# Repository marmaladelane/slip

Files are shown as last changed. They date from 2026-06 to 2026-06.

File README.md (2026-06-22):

# K1 Smart Lighting Interface to PIR (SLIP)

For the [Smart Lighting](https://github.com/marmaladelane/smart-lighting) project, we need a way to connect PIR sensors to the smart lighting controller.

The most common and easily available outdoor (weatherproof) PIR sensors are the mains-powered ones, usually used to control lights directly. In theory we should be able to monitor the switched live (SL) output from one of these devices, using a device with a mains voltage level input, such as a [Sonoff ZBMINIR2](https://help.sonoff.tech/docs/zbminir2).

Unfortunately, this [does not work](https://electronics.stackexchange.com/questions/769672/sonoff-zbminir2-switched-live-input-from-pir-sensor), probably because a snubber network inside the PIR sensor, across the relay output contacts, leaks enough current to trigger the Sonoff's AC input (S2) even when the output is off. I couldn't find an easy way to fix that except to place a relay between the PIR sensor's output and the Sonoff's input.

To connect the relay and make the wiring easier and safer, I designed this circuit board to hold the relay and switch and a set of screw terminals for each connection (live in, live out and PIR sensor):

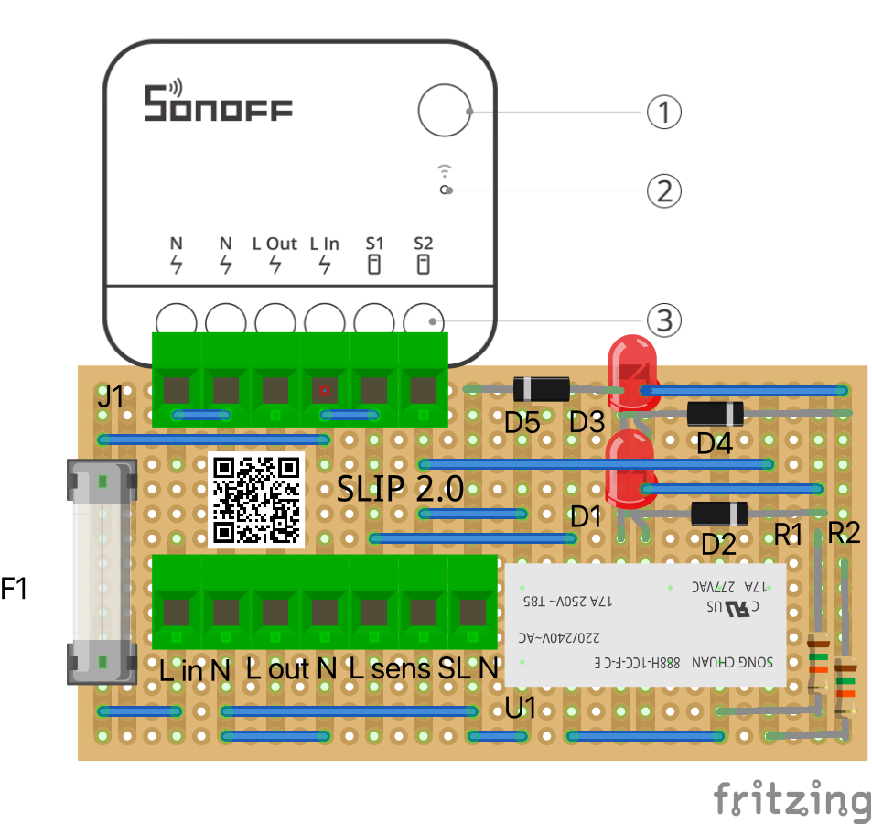
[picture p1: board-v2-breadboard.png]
Breadboard Image


You can open the [source file](board-v2.fzz) in [Fritzing](https://fritzing.org) (open source, small charge for binary download) or print the [printable PDF](board-v2-breadboard.pdf). There is also a PCB in the Fritzing file, but it's untested.

Many thanks to Roy Gwinn for reviewing my design and suggesting several changes to improve safety and reliability.

## Principle of operation

This is the circuit schematic:

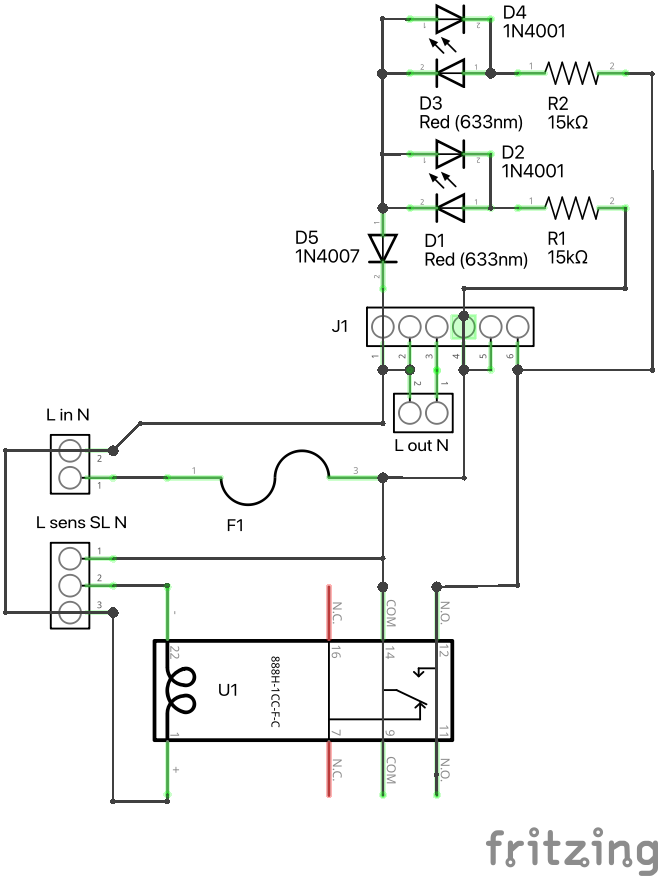
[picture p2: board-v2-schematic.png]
Circuit Schematic


The circuit is protected by a small glass fuse (e.g. 0.2 A) as the load is expected to be extremely low: just some small digital electronics, a small relay and a low-power Zigbee radio. The mains output (L out N) connector would normally be unused. If you use it, you may need a larger fuse, and you might want to double-check the resistance of the tracks, wires and solder joints.

* Live mains comes into the "L in N" connector.
* The live side goes through the small glass fuse F1 into the Sonoff (L In).
* The Sonoff internally connects L In to S1 (live out to the "switch"), and a jumper wire does too.
* Live (L In) connects via a capacitive dropper (C1) to the power LED (D1).
* S1 is connected to one side of the relay's switched contact.
* S2 is connected to the other side of the relay's switched contact.
* S1 is also connected to the power supply for the PIR sensor (L sens).
* The PIR sensor's switched live output (SL) is connected to one side of the coil of the relay (U1).
* The other side of the coil is connected to neutral (N).
* When the PIR sensor's output is high, the coil magnetises and closes the contact, sending the live signal to the Sonoff (S2).

The Sonoff should be configured to send a signal to the smart lighting controller (HomeAssistant) when its switch input (S2) is active.

## Safety warning

### ⚠️ WARNING: This circuit uses live mains voltage, which can kill!

The risks include:

* Fire,
* Electric shock,
* Personal injury,
* Property damage,
* Death.

Neither the Sonoff device nor this home-made board are CE approved. If you follow these instructions, it is **entirely at your own risk**.

Do not attempt to build this circuit unless you are sufficiently skilled and comfortable with soldering, and observe all sensible safety precautions, including but not limited to:

* Test the circuit thoroughly before connecting to the mains, as described below under Testing.
* Install appropriate fuses (the minimum possible values) on the board and its AC mains voltage supply.
* Always use a [residual current device](https://www.screwfix.com/p/masterplug-13a-unfused-plug-through-active-rcd-adaptor/63731) when connecting to mains, especially during development.
* Always double-check that power is disconnected before touching the board (e.g. visual check, use a voltage tester and check the power LED).
* Keep an electrical-safe (not red/water) fire extinguisher nearby during development.
* Never leave the board powered unattended indoors.
* Clean (e.g. with isopropyl alcohol) and PAT test the finished board.
* Only permanently install the board outdoors, away from flammable materials.
* Permanently install the board in a sealed, waterproof box which cannot be opened accidentally.
* Protect the board from water by sealing all holes in the box with rubber grommets and cable glands.

## Bill of materials

| Component | Code  | Qty | Cost  | Link | Notes |
| --- | ----- | --- | ----- | ---- | ----- |
| Stripboard  | | 1 | £4.80 | https://cpc.farnell.com/kemo-electronic/e005/stripboard-fr4-100x160mm/dp/PC01603 |
| Fuse holder | F1 | 1 | £0.67 | https://uk.rs-online.com/web/p/fuse-holders/8930574 |
| Glass fuse  | 0.2 A | 1 | £0.06 | https://www.amazon.co.uk/dp/B0CD1Z6TDH | 
| Resistor | R1,R2 | 2 | £0.44 | https://uk.rs-online.com/web/p/through-hole-resistors/6835798P | 2W metal film 47k ohms |
| LED | D1,D3 | 2 | £0.85 | https://uk.rs-online.com/web/p/leds/7133936P | High brightness 3mm green LED recommended |
| Diode | D2,D4 | 2 | £0.12 | https://uk.rs-online.com/web/p/schottky-diodes-rectifiers/6491143 | 1N4007, 1kV rated |
| Sonoff connector | J1 | 1 | £2.54 | https://uk.rs-online.com/web/p/pcb-headers/1800623 | 0.2" pin spacing to mate with Sonoff |
| PCB Power Relay | U1 | 1  | £5.53 | https://uk.rs-online.com/web/p/power-relays/6803820P | 230V AC Coil |
| PCB terminal, 2 way | L in/out| 2 | £1.08 | https://cpc.farnell.com/camdenboss/ctb3000-2/pcb-terminal-45deg-low-prof-5mm/dp/CN19467 | 45 Degree Low Profile, 5mm spacing |
| PCB terminal, 3 way | L sens | 1 | £0.87 | https://cpc.farnell.com/camdenboss/ctb3000-3/pcb-terminal-45deg-low-prof-5mm/dp/CN19468 | 45 Degree Low Profile, 5mm spacing |
| PIR sensor (typical) | | 1 | £15.98 | https://www.screwfix.com/p/zink-dion-indoor-outdoor-white-pir-twin-sensor-180-/718fh | With switched live output |
| Jumper wires | | 1 | £6.39 | https://www.amazon.co.uk/Breadboard-Jumper-Wires-DIY-Accessories/dp/B0D5M9DN2K/ | Optional, but will save you a lot of time |

In addition, you will need a case large enough for the circuit board and sonoff (about 72x72 mm internal space):

* Either plug into a 13A outdoor wall socket, in which case an [outdoor junction box](https://www.amazon.co.uk/dp/B0156QPJNU) is fine ([this one](https://www.toolstation.com/spelsberg-ip65-junction-box/p61729) is slightly smaller).
* Or wired into the outdoor lighting circuit, in which case a [fused spur](https://www.toolstation.com/bg-ip66-spur/p25211) is required to allow easy and safe isolation, and the board can be mounted inside the same case.

And you might want to use rigid 20mm [conduit](https://www.screwfix.com/p/deta-tte-round-upvc-black-conduit-20mm-x-3m/580vt), [elbows](https://www.screwfix.com/p/deta-tte-black-inspection-elbow-20mm/187vt) and [adaptors](https://www.screwfix.com/p/deta-tte-female-conduit-adaptors-20mm-black-2-pack/907vt) to keep the cable protected, safe and tidy.

## Build process

Mark the stripboard to size of outline of board, plus any edges, cutouts and holes needed to hold it in place inside its case (see above). Ensure that the strips run in the correct direction before cutting!

Print out a copy of the breadboard layout, and glue it to the top side of the board (you can use pritt stick for this). Ensure that the holes on the print line up with the holes pre-drilled in the board before the glue sets:

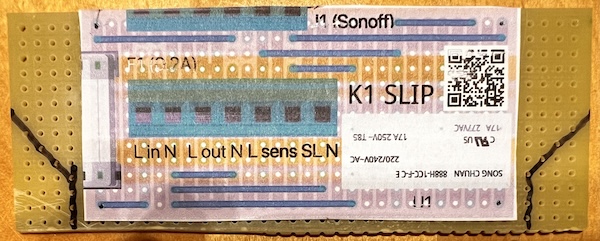
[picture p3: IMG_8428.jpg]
Breadboard with printed layout glued on


Cut along the lines with a junior hacksaw. Cut from the edges towards the middle of the board, otherwise it may snap. Sand down the sharp cut edges for safety.

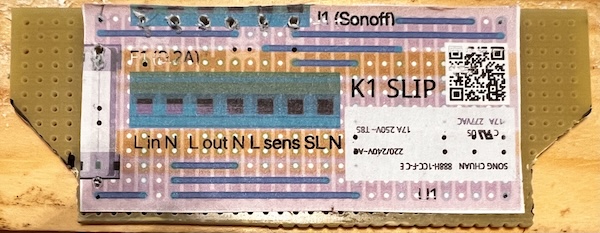
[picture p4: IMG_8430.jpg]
Breadboard cut to shape


Some of the copper tracks on the underside must be **removed completely**. They are shown on the breadboard as having tracks cut between every hole. They are columns 3, 5, 7, 9, 11, 13, 15, 17, 19, 21, 24, 25, 27, 29. Poke a pin through the paper somewhere on each of these rows, so you can see through the hole from the other side. Turn the board over (copper side up), identify the rows marked with these holes, and remove each one in turn. Use a soldering iron to weaken the glue and get a scalpel under one end. Then using pliers to pull, run the soldering iron along the track and lift away the copper. If you go too fast it tears, too slow and it burns the SRBP. Practice is needed.

The copper track must also be cut in some places:

* Between the pins of the fuse (F1) (two holes cut).
* Between the Sonoff (J1) left neutral (N) pin and the *L in* terminal, left of the QR code (two holes cut).
* Between the *L In* pin of the Sonoff (J1) and the *N out* terminal, right of the QR code (two holes cut).
* Below the right-hand pin of LED D3, above LED D1 (unfortunately hidden behind D1 on the breadboard view).
* Between the SL terminal and the Sonoff (J1) pin S2.
* Between the top and bottom coil pins of the relay (U1), above the *U1* label (two holes cut).o

Poke a pin through the paper (into the pre-drilled hole below) where the where the tracks should be cut, so you can see through the holes from the other side, then gently drill with a 4mm bit from the other side, **not** all the way through the board, just enough to break the copper track completely (both sides):

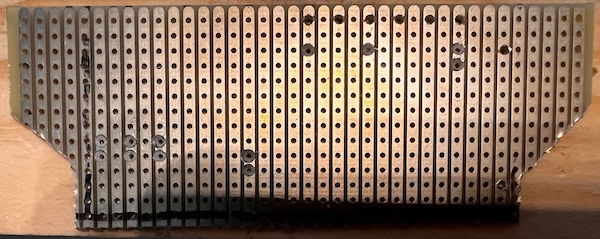
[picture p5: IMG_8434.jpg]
Breadboard reverse with tracks cut


Some of the pre-drilled holes need to be enlarged to take the larger pins of some components:

* The Sonoff connector (J1).
* The PCB terminals (in, out, sens).
* The fuse holder (F1).

Use the actual terminal blocks to determine where the pins are that should be drilled through, not the green markings on the breadboard image (these are a different type of terminal blocks).

Poke a pin through each of these holes, then drill through with a 1.5mm bit.

Poke a pin through the holes at each end of each jumper wire. Cut wires to length (or use pre-formed breadboard jumper wires) and mount on the board. Ignore the other components already mounted in this photo, it's better to mount all the wires first:

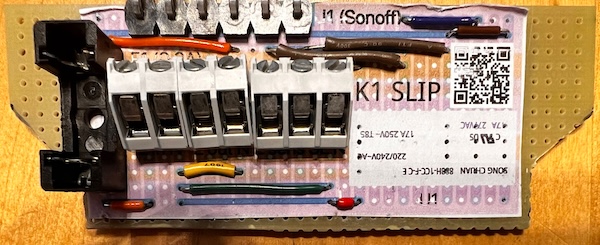
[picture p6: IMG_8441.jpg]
Breadboard with wires mounted


On the underside of the board, bend the bare wire ends over to hold them in place, and solder them:

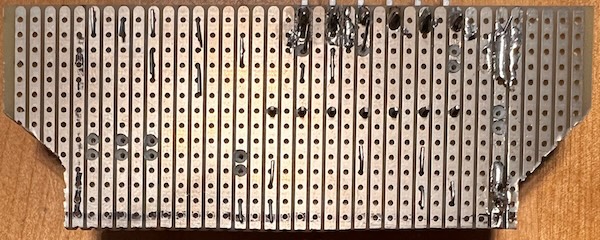
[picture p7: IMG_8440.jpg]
Breadboard with wire ends bent over


Poke a pin through all remaining component holes (R1-2, D1-5, U1). Mount and solder the remaining components onto the board (see photo above). **Leave R1 and R2 to last**, as they need to be bent into special shapes to act as jumper wires, and their leads must not touch each other or any other component or wire. Clip the PCB terminals together before soldering them, so they don't sit awkwardly like mine did.

Clean off any remaining solder flux (e.g. with isopropyl alcohol) and inspect the board for shorts, solder bridges and contamination.

## Testing

Test all the following **before** applying mains power.

With no wires connected to the PCB terminals, no glass fuse installed, no Sonoff installed, you should have:

* No continuity across track breaks.
* No shorts between adjacent tracks (test both sides of each track break separately).
* No continuity across the fuse holder (F1).
* High resistance (about 35k ohms) across the coil of the relay.
* No continuity between the centre and NO contacts of the relay U1.
* Continuity between the north side of the fuse holder and:
  * *L In* and *S1* on the Sonoff,
  * the *L sens* terminal,
  * the right-hand side of resistor R1,
  * the centre contact of relay U1.
* Continuity between the *SL* terminal and the upper side of the coil of relay U1.
* Continuity between the *N in* terminal and:
  * The lower side of the coil of relay U1,
  * The other two N terminals,
  * The N pin of the Sonoff (J1).
* No continuity between any of the Live terminals and any of the Neutral terminals.

With no glass fuse (F1) or Sonoff (J1) installed, connect mains power to *L in N* and verify that the power LED (D1) does not light, and there is no power (250V AC) to any terminal except *L in*.

Power off and install a glass fuse in F1. Power on and check that the Sonoff pin 4 (*L In*) and *L sens* are live (250V AC) and the power LED (D1) lights.

Power off and install the Sonoff on J1. Power on and check that its LED flashes.

Power off and connect the PIR sensor to *L send SL N*. Power on and check that the relay clicks and the switch LED (D3) lights briefly when the power is applied or when the PIR sensor is triggered.

Add the Sonoff to the eWeLink app on a phone and check that its output (shown in the app) goes high when the PIR sensor is triggered (and D3 is lit), and off when the PIR sensor relaxes (and D3 is off).

PAT test the finished circuit.

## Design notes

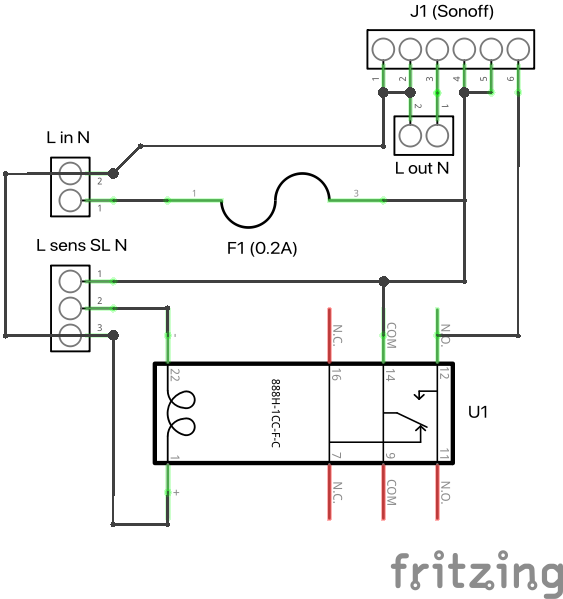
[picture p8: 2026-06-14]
board-v1-schematic.png

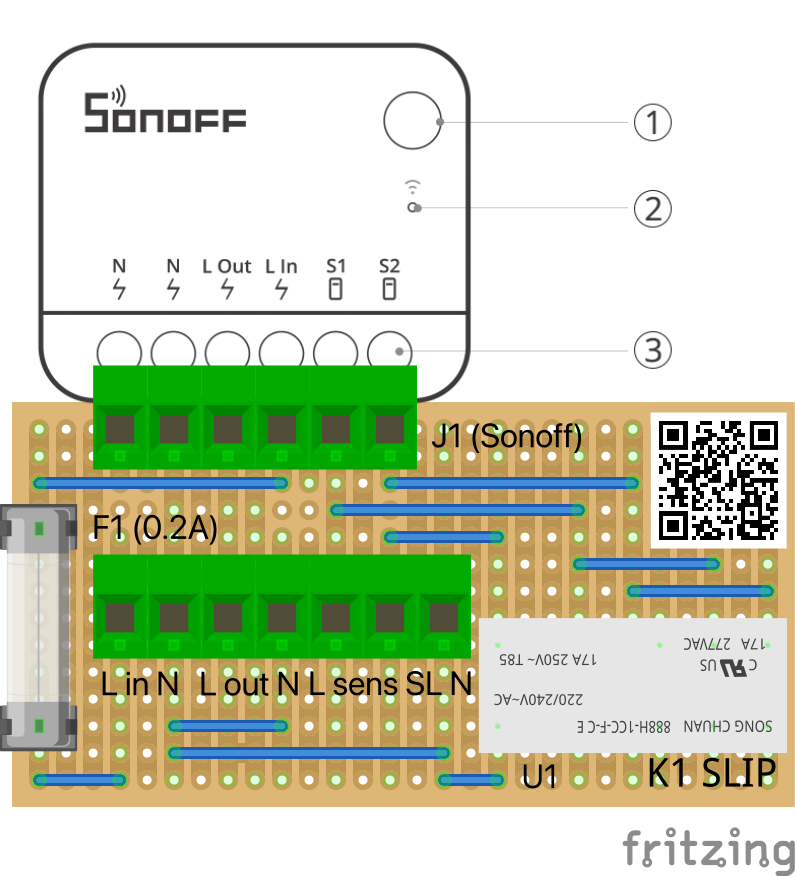
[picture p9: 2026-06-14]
board-v1-breadboard.png

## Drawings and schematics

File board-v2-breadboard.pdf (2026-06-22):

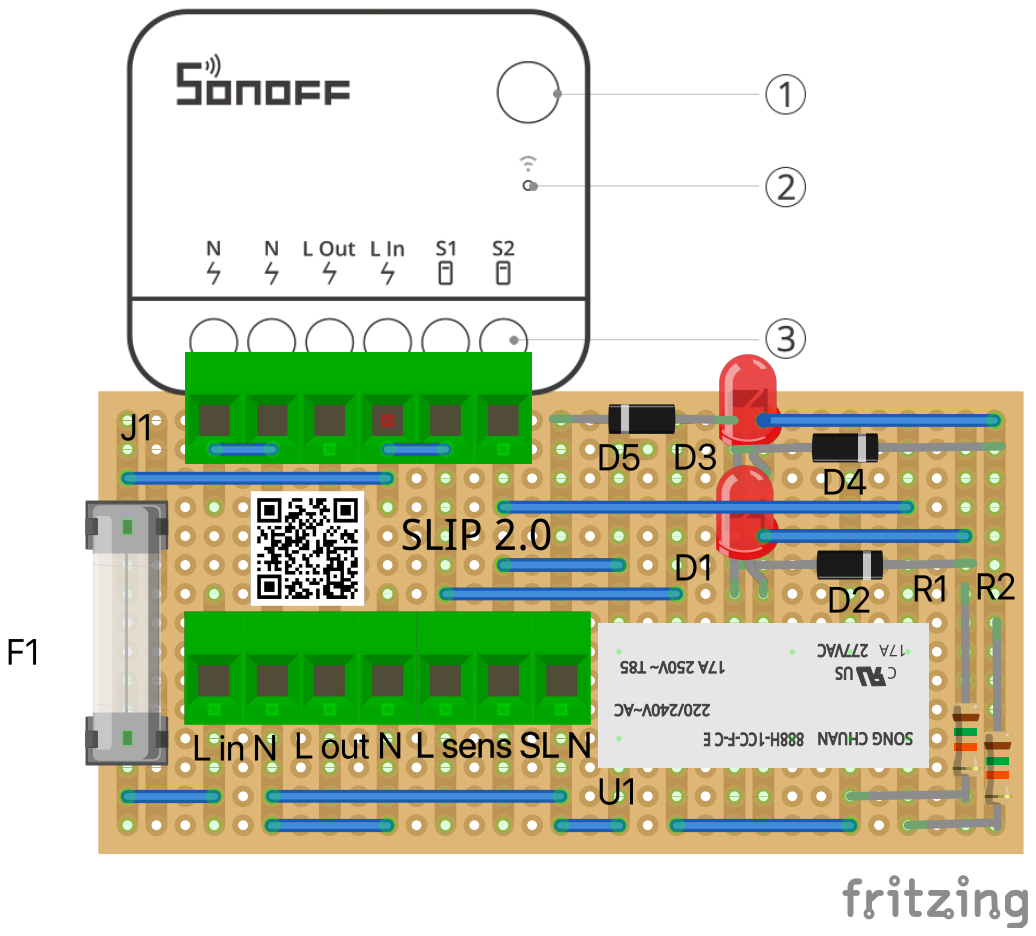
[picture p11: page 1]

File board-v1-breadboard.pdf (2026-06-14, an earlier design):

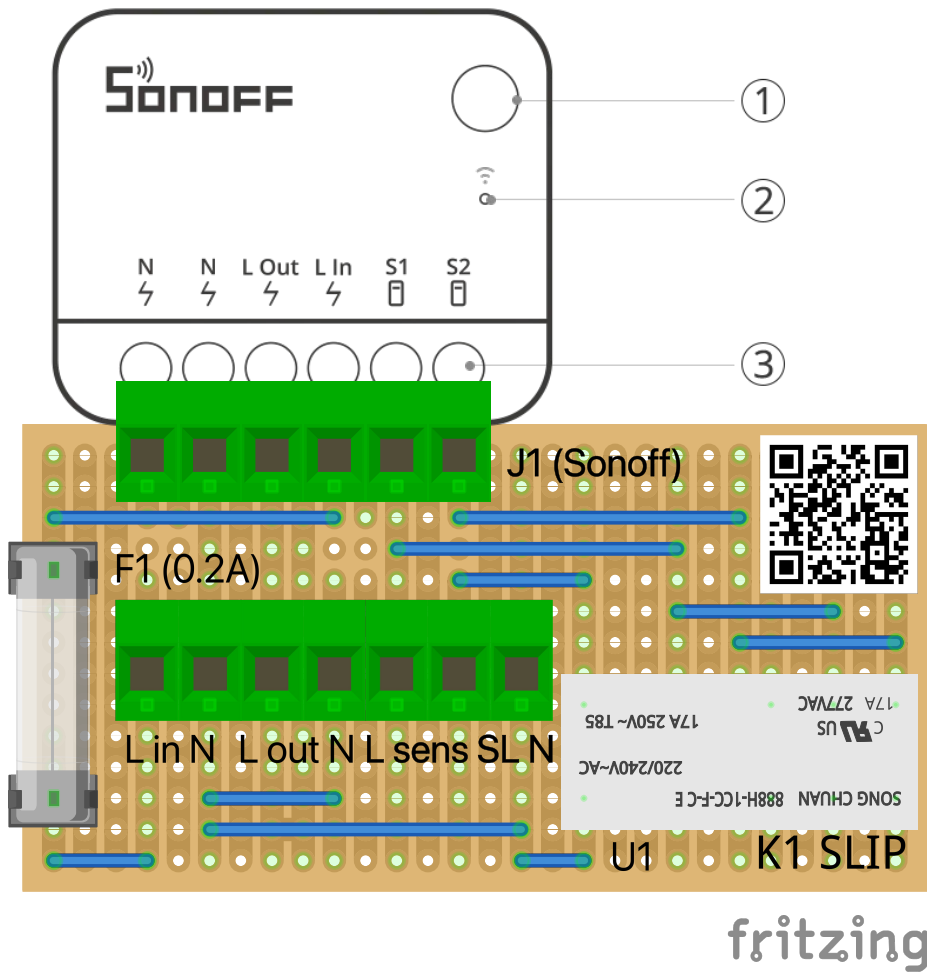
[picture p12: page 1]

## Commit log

2026-06-10 Add circuit board designed in Fritzing (first version)
    [board-v1.fzz]
2026-06-14 Add V2 board, README and images
    [board-v1.fzz, board-v2.fzz]
2026-06-14 README: add testing instructions, fix table
    [board-v2.fzz]
2026-06-17 Add status LEDs to V2 board, update list of parts
    [board-v2.fzz]
2026-06-22 Update board design with Roy Gwinn's suggestions
    [board-v2.fzz]
